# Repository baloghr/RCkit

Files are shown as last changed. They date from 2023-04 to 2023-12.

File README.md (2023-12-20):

# RCkit
Simple RC kit for teaching basics of control system

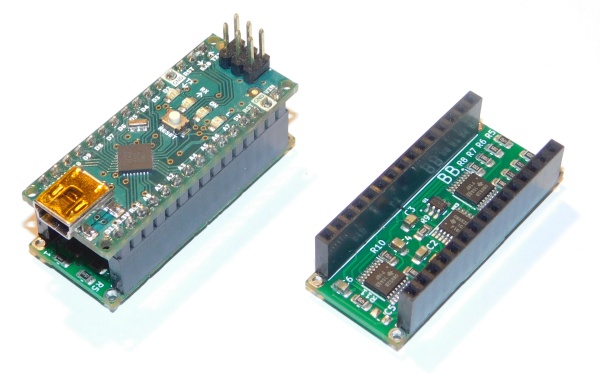
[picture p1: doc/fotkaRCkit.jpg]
Photo of the board Photo of the board with Arduino Nano installed and the board itself.


It is a simple extension board (shield) for Arduino Nano, but connectible also to any other Arduinos. Board contains few RC circuits creating a system of modules representing the 1st and/or 2nd order systems in various configurations. User can control the system from the Arduino using e.g. PID control algorithms and measure the system responses. Combination with Matlab/Simulink is also possible. 

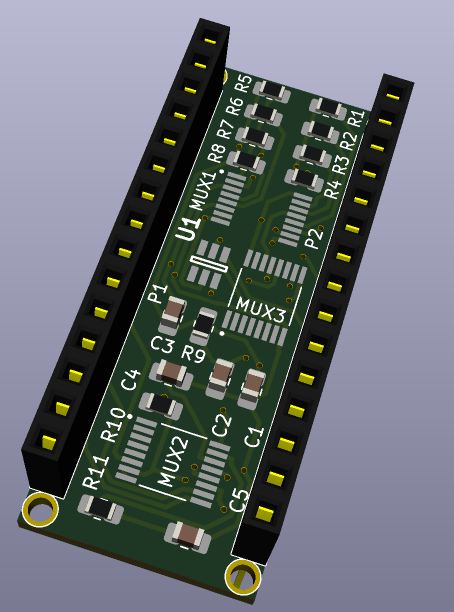
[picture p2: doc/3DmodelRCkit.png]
3D model 3D model of the board


Initial design was done by students András Blahó and Filip Brhlík during their diploma projects. 

More information can be found in the following paper:

Žáková, Katarína and Richard Balogh. "Control Engineering Home Learning Kit." IFAC-PapersOnLine, vol. 55, no. 4, 1 Jan. 2022, pp. 310-5, doi:10.1016/j.ifacol.2022.06.051.

The paper is available at the https://www.sciencedirect.com/science/article/pii/S2405896322003664

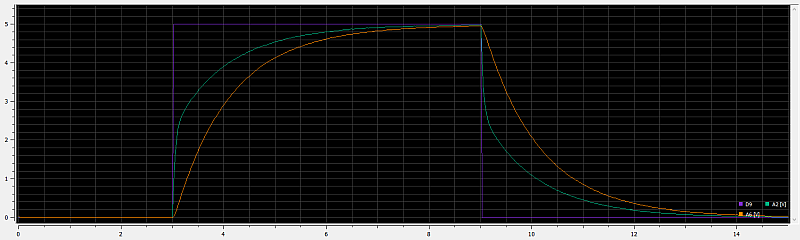
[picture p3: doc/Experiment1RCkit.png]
Experiment An example experiment with the board.


See also a configuration diagram of the system

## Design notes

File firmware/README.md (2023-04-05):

Firmware for an Arduino to test the system

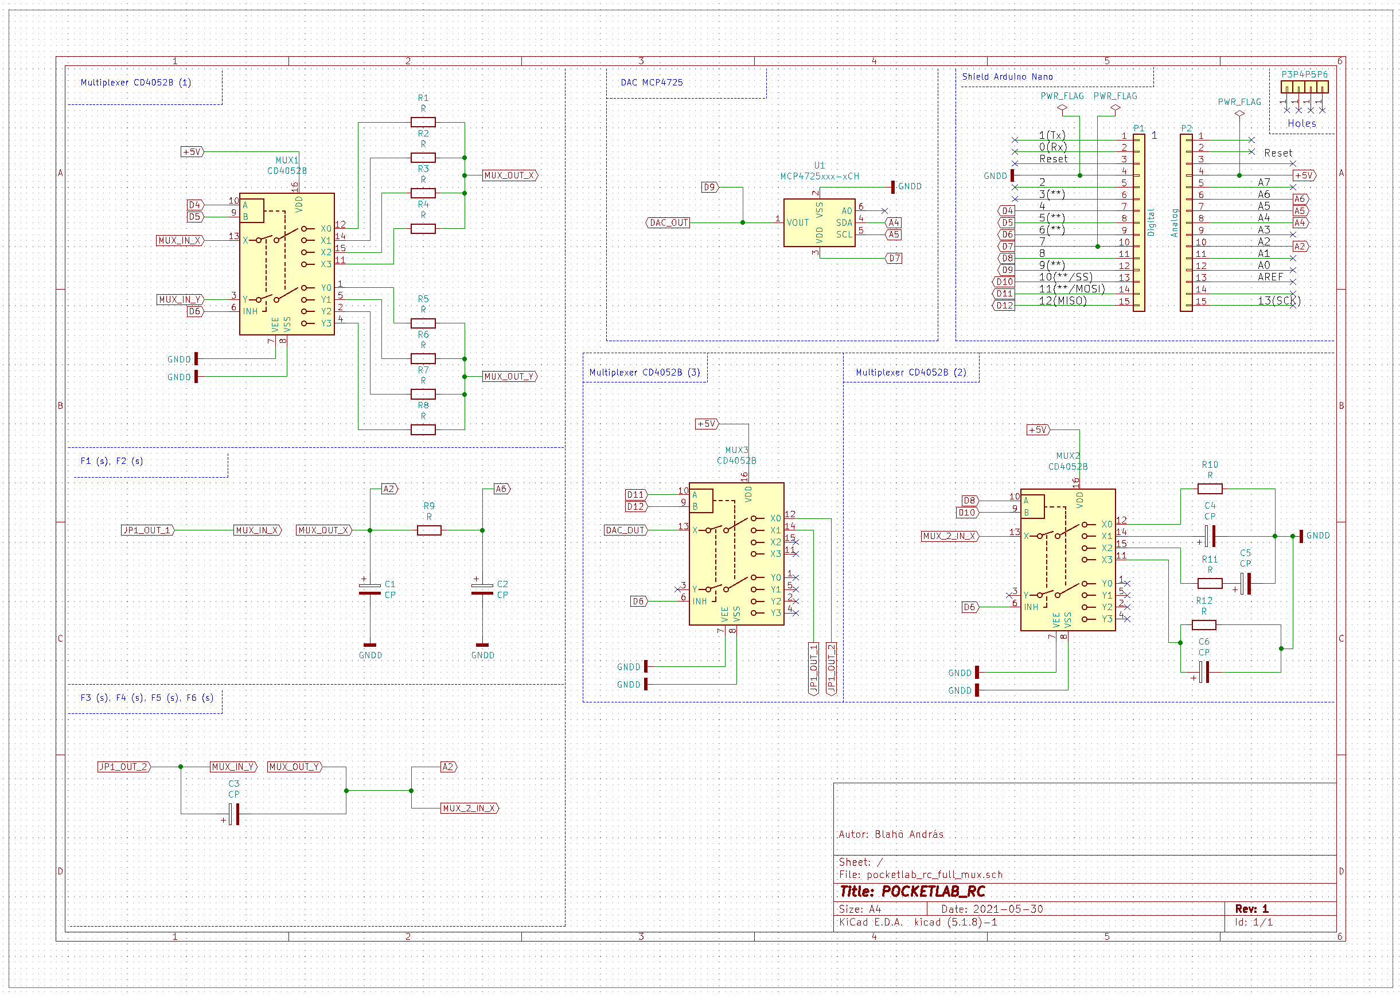
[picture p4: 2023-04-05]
doc/schema.png

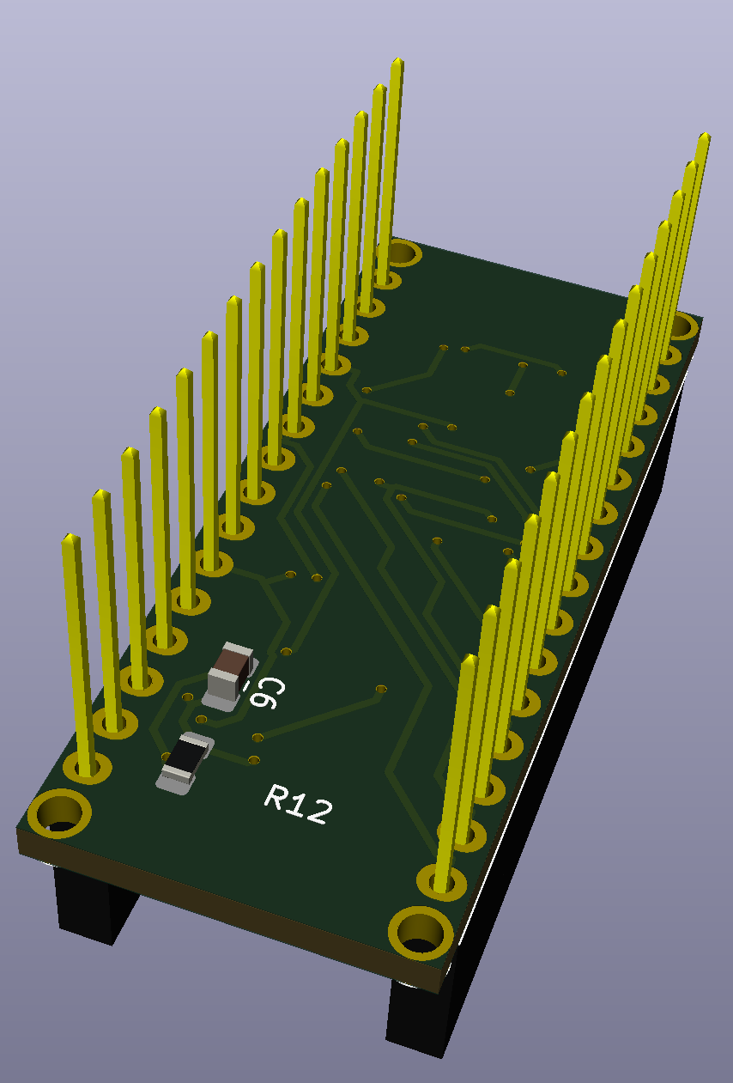
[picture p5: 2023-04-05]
doc/3D_2.png

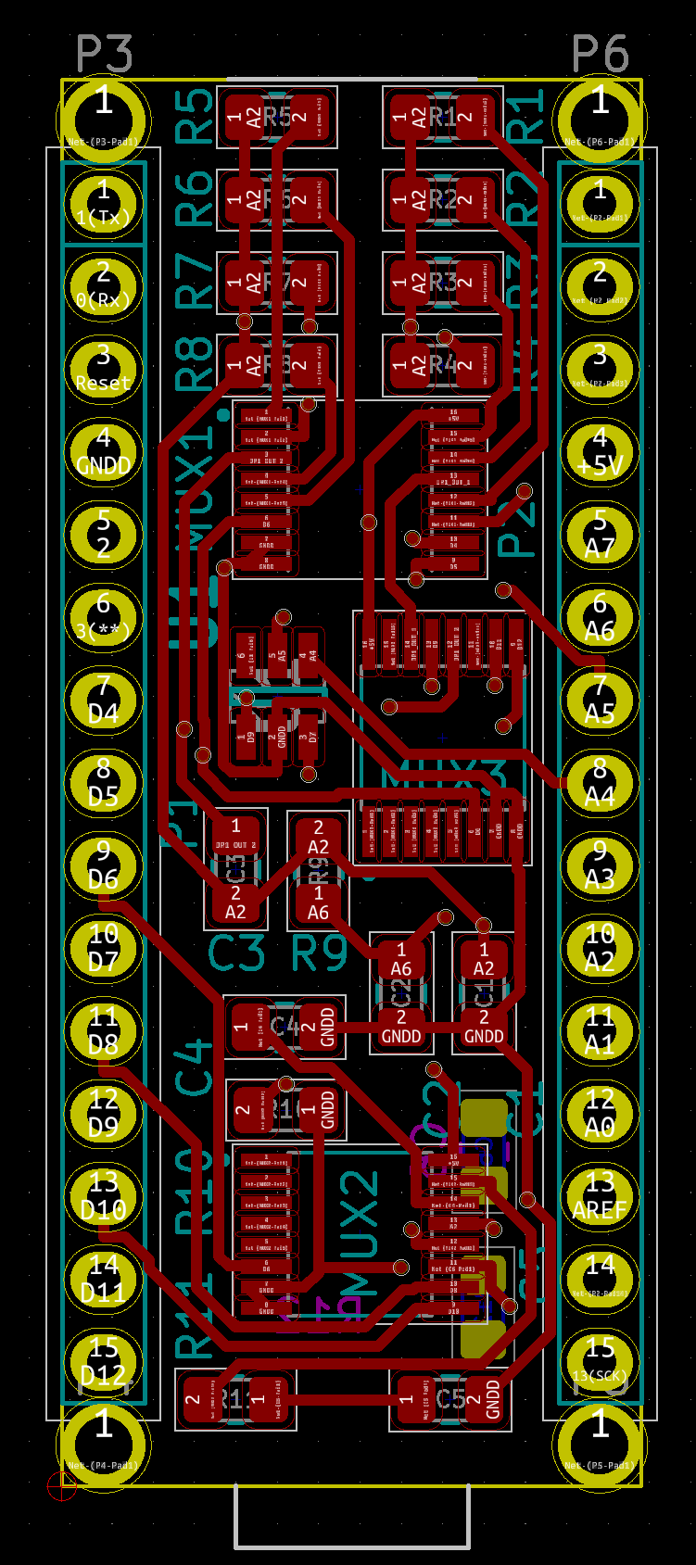
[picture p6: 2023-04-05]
doc/pcb.png

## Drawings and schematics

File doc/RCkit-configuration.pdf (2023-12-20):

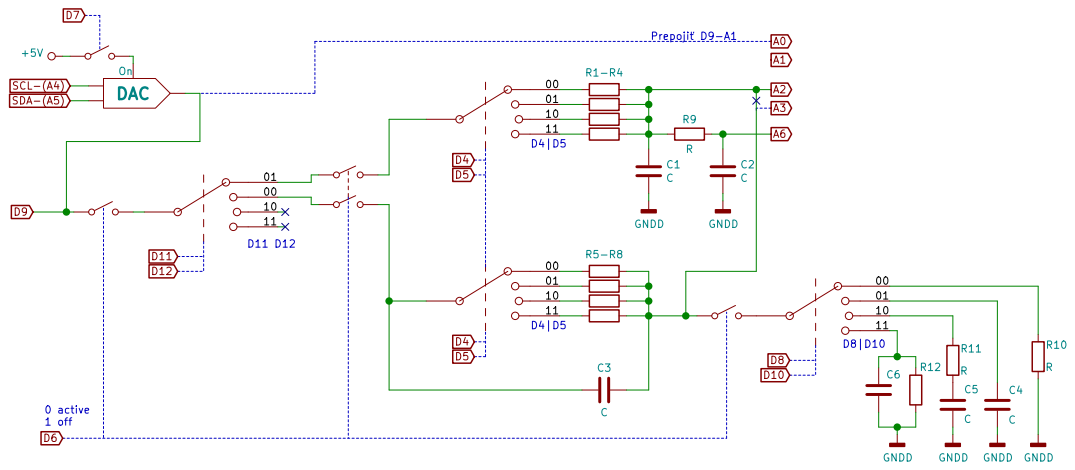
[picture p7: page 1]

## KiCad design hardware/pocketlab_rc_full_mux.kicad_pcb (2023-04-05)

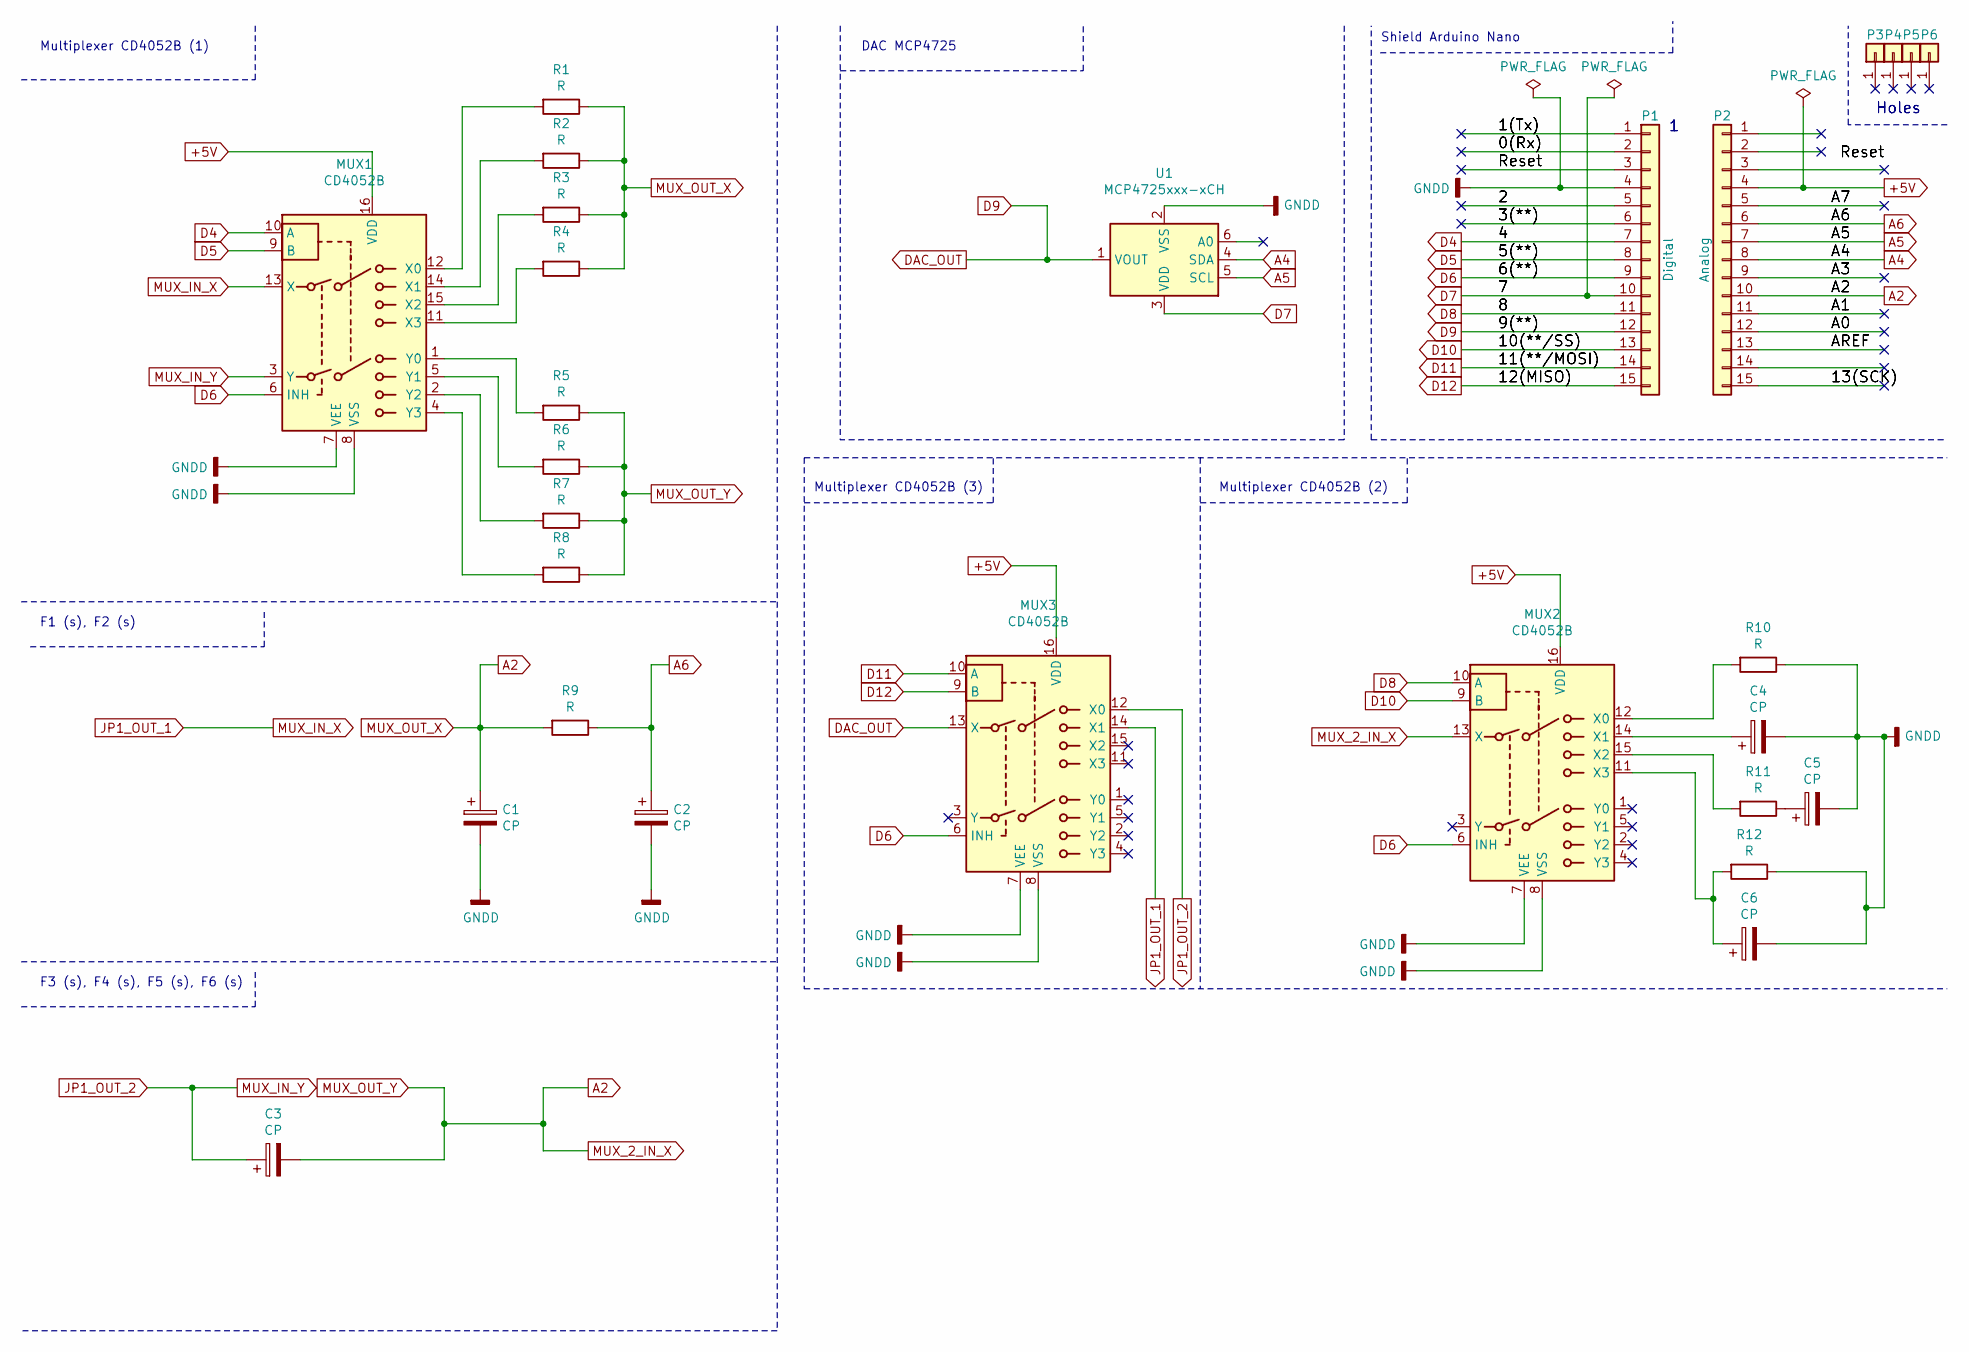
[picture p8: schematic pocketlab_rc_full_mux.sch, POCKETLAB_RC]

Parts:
C1, C2, C3, C4, C5, C6: CP; C_0805_2012Metric_Pad1.18x1.45mm_HandSolder
MUX1, MUX2, MUX3: CD4052B; SOP65P640X120-16N
P1: Digital; Socket_Strip_Arduino_1x15
P2: Analog; Socket_Strip_Arduino_1x15
P3, P4, P5, P6: CONN_01X01; 1pin_Nano
R1, R2, R3, R4, R5, R6, R7, R8, R9, R10, R11, R12: R; R_0805_2012Metric_Pad1.20x1.40mm_HandSolder
U1: MCP4725xxx-xCH; SOT95P270X145-6N

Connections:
+5V: MUX1.16 (VDD), MUX2.16 (VDD), MUX3.16 (VDD), P2.4
/0(Rx): P1.2
/1(Tx): P1.1
/2: P1.5
/3(**): P1.6
/13(SCK): P2.15
/A0: P2.12
/A1: P2.11
/A3: P2.9
/A7: P2.5
/AREF: P2.13
/Reset: P1.3
A2: C1.1, C3.2, MUX2.13 (X), P2.10, R1.1, R2.1, R3.1, R4.1, R5.1, R6.1, R7.1, R8.1, R9.2
A4: P2.8, U1.4 (SDA)
A5: P2.7, U1.5 (SCL)
A6: C2.1, P2.6, R9.1
D4: MUX1.10 (A), P1.7
D5: MUX1.9 (B), P1.8
D6: MUX1.6 (INH), MUX2.6 (INH), MUX3.6 (INH), P1.9
D7: P1.10, U1.3 (VDD)
D8: MUX2.10 (A), P1.11
D9: MUX3.13 (X), P1.12, U1.1 (VOUT)
D10: MUX2.9 (B), P1.13
D11: MUX3.10 (A), P1.14
D12: MUX3.9 (B), P1.15
GNDD: C1.2, C2.2, C4.2, C5.2, C6.2, MUX1.7 (VEE), MUX1.8 (VSS), MUX2.7 (VEE), MUX2.8 (VSS), MUX3.7 (VEE), MUX3.8 (VSS), P1.4, R10.1, R12.1, U1.2 (VSS)
JP1_OUT_1: MUX1.13 (X), MUX3.14 (X1)
JP1_OUT_2: C3.1, MUX1.3 (Y), MUX3.12 (X0)
unnamed: C4.1, MUX2.14 (X1)
unnamed: C5.1, R11.1
unnamed: C6.1, MUX2.11 (X3), R12.2
unnamed: MUX1.1 (Y0), R5.2
unnamed: MUX1.2 (Y2), R7.2
unnamed: MUX1.4 (Y3), R8.2
unnamed: MUX1.5 (Y1), R6.2
unnamed: MUX1.11 (X3), R4.2
unnamed: MUX1.12 (X0), R1.2
unnamed: MUX1.14 (X1), R2.2
unnamed: MUX1.15 (X2), R3.2
unnamed: MUX2.12 (X0), R10.2
unnamed: MUX2.15 (X2), R11.2

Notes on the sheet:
Holes
DAC MCP4725
Multiplexer CD4052B (1)
F1 (s), F2 (s)
Shield Arduino Nano
F3 (s), F4 (s), F5 (s), F6 (s)
Multiplexer CD4052B (2)
Multiplexer CD4052B (3)

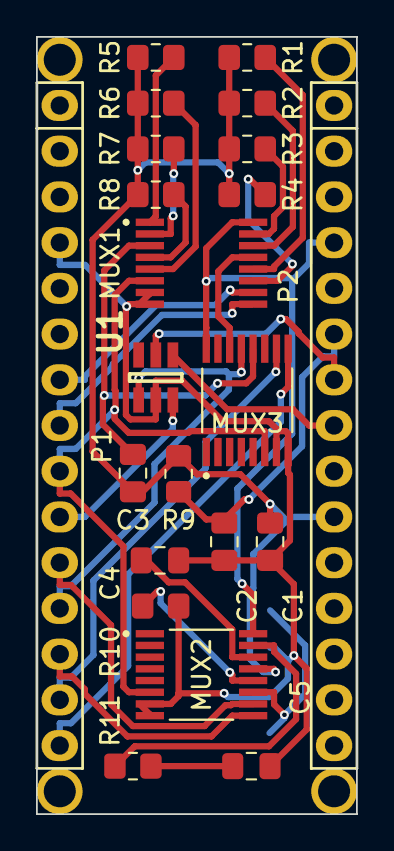
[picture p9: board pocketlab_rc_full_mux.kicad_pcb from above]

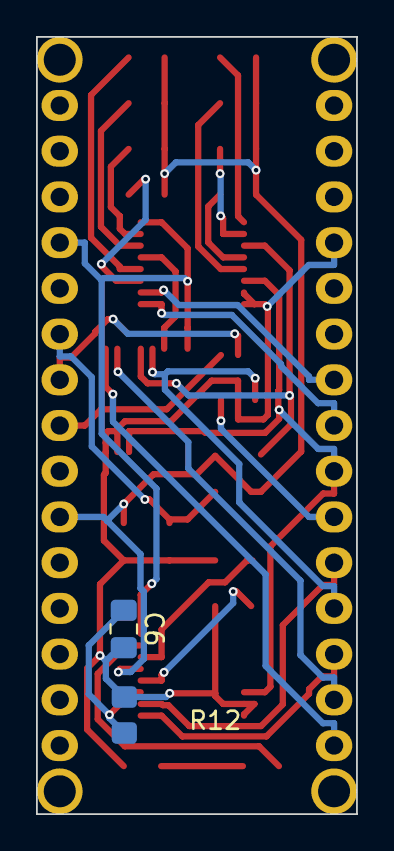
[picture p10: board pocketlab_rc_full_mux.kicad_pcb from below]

Board: 2 copper layers, 17.8 x 43.2 mm, 28 parts (2 on the bottom side), 30 nets.

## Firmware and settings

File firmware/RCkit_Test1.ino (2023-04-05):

void setup() 
{
       pinMode(6, OUTPUT);
  digitalWrite(6, HIGH);   // turn the Inhibit OFF


       pinMode(9, OUTPUT);
  digitalWrite(9, LOW);   // control signal OFF

       pinMode(4, OUTPUT);
  digitalWrite(4, LOW);    // S0 = 0
  
       pinMode(5, OUTPUT);
  digitalWrite(5, LOW);    // S1 = 0
  
  Serial.begin(115200);
}


void loop() {

 for (int i = 1; i<=100; i++)
   {
    Serial.print(analogRead(A2));
    Serial.print(",");
    Serial.println(analogRead(A6));
    Serial.println("");
    delay(2);
   }

  digitalWrite(6, LOW);   // turn the Inhibit OFF
  digitalWrite(9, HIGH);   // control signal ON

for (int i = 1; i<=1000; i++)
   {
    Serial.print(analogRead(A2));
    Serial.print(",");
    Serial.println(analogRead(A6));
    Serial.println("");
    delay(2);
   }   

  digitalWrite(9, LOW);   // control signal ON

for (int i = 1; i<=1000; i++)
   {
    Serial.print(analogRead(A2));
    Serial.print(",");
    Serial.println(analogRead(A6));
    Serial.println("");
    delay(2);
   }   

}

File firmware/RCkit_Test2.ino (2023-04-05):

// toto sme vyrobili v ArduBlockly co mam nainstalvane
// a potom som to trocha upravil, pretoze napriklad A6 sa nedalo vybrat

long oldTime;

void setup() 
{
  Serial.begin(115200);
  pinMode(4, OUTPUT);  // S0 (4052)
  pinMode(5, OUTPUT);  // S1 (4052)
  pinMode(6, OUTPUT);  // /En (4052)
  pinMode(9, OUTPUT);  // Output 0->1 charge, 1-> disch
  pinMode(A2, INPUT);  // Output of the system S1
  pinMode(A6, INPUT);  // Output of the system S2

  digitalWrite(6, HIGH);  // Inactivate 4052
  digitalWrite(9, LOW);   // Dischg. system
  digitalWrite(4, LOW);   // Channel 0/1
  digitalWrite(5, HIGH);   // Channel 0

  oldTime = millis();

  digitalWrite(6, LOW); // Activate 4052
  digitalWrite(9, LOW); // Dischg. again

  // toto je prva velka slucka na vynulovanie 3 sekundy
  while (oldTime < 3000) 
  {
    while (millis() - oldTime < 25) { /* len cakaj */ }
    
    Serial.println((String(oldTime) + String(",") + String(digitalRead(9)) + String(",") + String(analogRead(A2)) + String(",") + String(analogRead(A6))));
    oldTime = millis();
  }
  
  digitalWrite(9, HIGH);  // skok a zaciname nabijat

  // druha slucka dalsich 6 sekund
  
  while (oldTime < 9000) 
  {
    while (millis() - oldTime < 25) { /* len cakaj */ }
    
    Serial.println((String(oldTime) + String(",") + String(digitalRead(9)) + String(",") + String(analogRead(A2)) + String(",") + String(analogRead(A6))));
    oldTime = millis();
   }
  
  digitalWrite(9, LOW);  // a tu zasa vybijame


  // tretia slucka dalsich 6 sekund
  
  while (oldTime < 15000) 
  {
    while (millis() - oldTime < 25) { /* len cakaj */ }
    
    Serial.println((String(oldTime) + String(",") + String(digitalRead(9)) + String(",") + String(analogRead(A2)) + String(",") + String(analogRead(A6))));
    oldTime = millis();
   }

}
void loop() 
{
  /* tu uz nerobime nic */
}
